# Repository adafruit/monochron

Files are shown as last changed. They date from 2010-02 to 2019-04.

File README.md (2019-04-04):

# MONOCHRON Clock kit - Open source clock platform, make clocks!

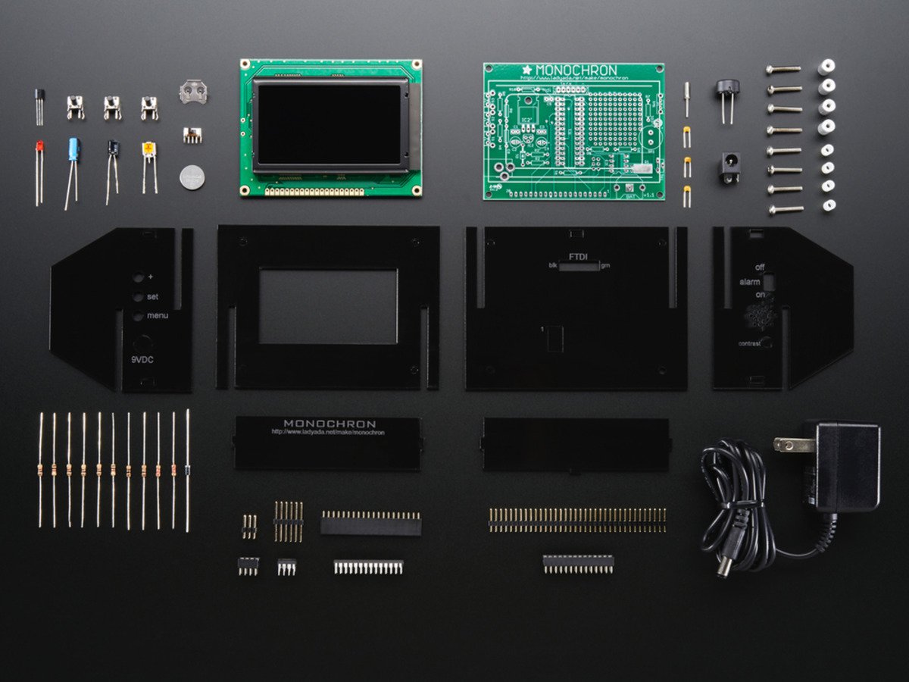
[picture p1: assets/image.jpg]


MONOCHRON® is a new clock kit from Adafruit! This easy kit is easily hackable to do whatever you wish, it's a clock platform - have fun!

- [128x64](https://learn.adafruit.com/system/assets/assets/000/010/412/original/lcd12864black.jpg) LCD (KS0108) - we special-ordered the black and white display!
- ATmega328 processor (we even stuck an 'arduino' stk500 bootloader on there too for hacking ease)
- [Laser cut enclosure in black acrylic](https://learn.adafruit.com/monochron/case-it)
- [Beeping/blinking alarm with 10 minute snooze](https://learn.adafruit.com/monochron/alarm)
- Battery backed-up real time clock ([DS1307](https://www.adafruit.com/partfinder/ic#rtc)) keeps time even when power is lost for years
- [European/US and 12/24 hour time display as well as date](https://learn.adafruit.com/monochron/date)
- [Completely open source hardware, all firmware, layout and CAD files are yours to mess with](https://learn.adafruit.com/monochron/download)
- Plenty of space for mods, a prototyping area for soldering stuff in

Comes with: clock kit (includes all parts, programmed chips and LCD), coin battery, enclosure, [9VDC power supply for 220V or 110V](https://www.adafruit.com/products/63)

The firmware shipped with the kit is for the Retro Arcade Table Tennis for Two as shown in the video below. We have other clock firmwares available on the project page if you would like to change the display. __This clock no longer includes the [FTDI Friend + extras](https://www.adafruit.com/products/284) for updating the MONOCHRON with new clocks__ We suggest picking one up if you want to reprogram the clock [(our tutorial for how to do this is on the MONOCHRON website.](https://learn.adafruit.com/monochron/updating).

You'll need some basic soldering & hand tools that are necessary to assemble it! The good news is that this is a pretty basic kit and even if its your first soldering project, it shouldn't take more than 2 or 3 hours to put together

For much more information including parts list, instructions, videos, etc. check out the [MONOCHRON website](https://learn.adafruit.com/monochron).

[MONOCHRON - open source retro clock](http://vimeo.com/9749504) from [adafruit industries](http://vimeo.com/adafruit) on [Vimeo](https://vimeo.com/).

- [Amanda 'w0z' Wozniak](http://praxical.blogspot.com/) - - designed the beautiful enclosure
- [Caitsith2](https://www.flickr.com/photos/48367508@N00/4389562355/) - beta-tested, and submitted some great firmware mods
- [Buro Vormkijgers](http://www.burovormkrijgers.nl/) - Inspired many people relive the joy of their retro-youth (__we are in no way associated with Buro Vormkijgers__, at the request of Sander Mulder on 4/10/2010 we've included a [link to his site here](http://www.sandermulder.com/pong_clock.html).)

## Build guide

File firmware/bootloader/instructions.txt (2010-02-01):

We're using the classic Arduino bootloader but for the internal 8MHz oscillator. 
Edit the makefile for your type of programmer and type in "make atmega328_prores_isp"

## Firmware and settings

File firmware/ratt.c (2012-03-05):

/* ***************************************************************************
// ratt.c - the time, init and main loop
// This code is distributed under the GNU Public License
//		which can be found at http://www.gnu.org/licenses/gpl.txt
//
**************************************************************************** */

#include <avr/io.h>      // this contains all the IO port definitions
#include <avr/interrupt.h>
#include <util/delay.h>
#include <avr/pgmspace.h>
#include <avr/eeprom.h>
#include <avr/wdt.h>
#include <string.h>
#include <i2c.h>
#include <stdlib.h>
#include "util.h"
#include "ratt.h"
#include "ks0108.h"
#include "glcd.h"


volatile uint8_t time_s, time_m, time_h;
volatile uint8_t old_h, old_m;
volatile uint8_t timeunknown = 1;
volatile uint8_t date_m, date_d, date_y;
volatile uint8_t alarming, alarm_on, alarm_tripped, alarm_h, alarm_m;
volatile uint8_t displaymode;
volatile uint8_t volume;
volatile uint8_t sleepmode = 0;
volatile uint8_t region;
volatile uint8_t time_format;
extern volatile uint8_t screenmutex;
volatile uint8_t minute_changed = 0, hour_changed = 0;
volatile uint8_t score_mode_timeout = 0;
volatile uint8_t score_mode = SCORE_MODE_TIME;
volatile uint8_t last_score_mode;

// These store the current button states for all 3 buttons. We can 
// then query whether the buttons are pressed and released or pressed
// This allows for 'high speed incrementing' when setting the time
extern volatile uint8_t last_buttonstate, just_pressed, pressed;
extern volatile uint8_t buttonholdcounter;

extern volatile uint8_t timeoutcounter;

// How long we have been snoozing
uint16_t snoozetimer = 0;

SIGNAL(TIMER1_OVF_vect) {
  PIEZO_PORT ^= _BV(PIEZO);
}

volatile uint16_t millis = 0;
volatile uint16_t animticker, alarmticker;
SIGNAL(TIMER0_COMPA_vect) {
  if (millis)
    millis--;
  if (animticker)
    animticker--;

  if (alarming && !snoozetimer) {
    if (alarmticker == 0) {
      alarmticker = 300;
      if (TCCR1B == 0) {
	TCCR1A = 0; 
	TCCR1B =  _BV(WGM12) | _BV(CS10); // CTC with fastest timer
	TIMSK1 = _BV(TOIE1) | _BV(OCIE1A);
	OCR1A = (F_CPU / ALARM_FREQ) / 2;
      } else {
	TCCR1B = 0;
	// turn off piezo
	PIEZO_PORT &= ~_BV(PIEZO);
      }
    }
    alarmticker--;    
  }
}

void init_eeprom(void) {	//Set eeprom to a default state.
  if(eeprom_read_byte((uint8_t *)EE_INIT) != EE_INITIALIZED) {
    eeprom_write_byte((uint8_t *)EE_ALARM_HOUR, 8);
    eeprom_write_byte((uint8_t *)EE_ALARM_MIN, 0);
    eeprom_write_byte((uint8_t *)EE_BRIGHT, OCR2A_VALUE);
    eeprom_write_byte((uint8_t *)EE_VOLUME, 1);
    eeprom_write_byte((uint8_t *)EE_REGION, REGION_US);
    eeprom_write_byte((uint8_t *)EE_TIME_FORMAT, TIME_12H);
    eeprom_write_byte((uint8_t *)EE_SNOOZE, 10);
    eeprom_write_byte((uint8_t *)EE_INIT, EE_INITIALIZED);
  }
}

int main(void) {
  uint8_t inverted = 0;
  uint8_t mcustate;
  uint8_t display_date = 0;

  // check if we were reset
  mcustate = MCUSR;
  MCUSR = 0;
  
  //Just in case we were reset inside of the glcd init function
  //which would happen if the lcd is not plugged in. The end result
  //of that, is it will beep, pause, for as long as there is no lcd
  //plugged in.
  wdt_disable();

  // setup uart
  uart_init(BRRL_192);
  DEBUGP("RATT Clock");

  // set up piezo
  PIEZO_DDR |= _BV(PIEZO);

  DEBUGP("clock!");
  clock_init();
  init_crand();	//Initialize the seed based upon current time.  Very first value discarded.
  //beep(4000, 100);

  init_eeprom();
  region = eeprom_read_byte((uint8_t *)EE_REGION);
  time_format = eeprom_read_byte((uint8_t *)EE_TIME_FORMAT);
  DEBUGP("buttons!");
  initbuttons();

  setalarmstate();

  // setup 1ms timer on timer0
  TCCR0A = _BV(WGM01);
  TCCR0B = _BV(CS01) | _BV(CS00);
  OCR0A = 125;
  TIMSK0 |= _BV(OCIE0A);

  // turn backlight on
  DDRD |= _BV(3);
#ifndef BACKLIGHT_ADJUST
  PORTD |= _BV(3);
#else
  TCCR2A = _BV(COM2B1); // PWM output on pin D3
  TCCR2A |= _BV(WGM21) | _BV(WGM20); // fast PWM
  TCCR2B |= _BV(WGM22);
  OCR2A = OCR2A_VALUE;
  OCR2B = eeprom_read_byte((uint8_t *)EE_BRIGHT);
#endif

  DDRB |= _BV(5);
  beep(4000, 100);
  
  //glcdInit locks and disables interrupts in one of its functions.  If the LCD is not
  //plugged in, glcd will run forever.  For good reason, it would be desirable to know
  //that the LCD is plugged in and working correctly as a result.  This is why we are
  //using a watch dog timer.  The lcd should initialized in way less than 500 ms.
  wdt_enable(WDTO_2S);
  glcdInit();
  glcdClearScreen();

  initanim();
  initdisplay(0);

  while (1) {
    animticker = ANIMTICK_MS;

    // check buttons to see if we have interaction stuff to deal with
	if(just_pressed && alarming)
	{
	  just_pressed = 0;
	  setsnooze();
	}
	if(display_date==1 && !score_mode_timeout)
	{
		display_date=3;
		score_mode = SCORE_MODE_DATELONG;
	    score_mode_timeout = 3;
	    setscore();
	}
	else if(display_date==2 && !score_mode_timeout)
	{
		display_date=3;
		score_mode = SCORE_MODE_DATE;
	    score_mode_timeout = 3;
	    setscore();
	}
	else if(display_date==3 && !score_mode_timeout)
	{
		display_date=0;
		score_mode = SCORE_MODE_YEAR;
	    score_mode_timeout = 3;
	    setscore();
	}
	/*if(display_date && !score_mode_timeout)
	{
	  if(last_score_mode == SCORE_MODE_DATELONG)
	  {
	    score_mode = SCORE_MODE_DOW;
	    score_mode_timeout = 3;
	    setscore();
	  }
	  
	  else if(last_score_mode == SCORE_MODE_DOW)
	  {
	    score_mode = SCORE_MODE_DATE;
	    score_mode_timeout = 3;
	    setscore();
	  }
	  else if(last_score_mode == SCORE_MODE_DATE)
	  {
	    score_mode = SCORE_MODE_YEAR;
	    score_mode_timeout = 3;
	    setscore();
	    display_date = 0;
	  }
	  
	}*/
	/*if(display_date && !score_mode_timeout)
	{
	  score_mode = SCORE_MODE_YEAR;
	  score_mode_timeout = 3;
	  setscore();
	  display_date = 0;
	}*/

    //Was formally set for just the + button.  However, because the Set button was never
    //accounted for, If the alarm was turned on, and ONLY the set button was pushed since then,
    //the alarm would not sound at alarm time, but go into a snooze immediately after going off.
    //This could potentially make you late for work, and had to be fixed.
	if (just_pressed & 0x6) {
	  just_pressed = 0;
	  if((region == REGION_US) || (region == REGION_EU)) {
	  	display_date = 3;
	  	score_mode = SCORE_MODE_DATE;
	  }
	  else if ((region == DOW_REGION_US) || (region == DOW_REGION_EU)) {
	  	display_date = 2;
	  	score_mode = SCORE_MODE_DOW;
	  }
	  else if (region == DATELONG) {
	  	display_date = 3;
	  	score_mode = SCORE_MODE_DATELONG;
	  }
	  else {
	  	display_date = 1;
	  	score_mode = SCORE_MODE_DOW;
	  }
	  score_mode_timeout = 3;
	  setscore();
	}

    if (just_pressed & 0x1) {
      just_pressed = 0;
      display_date = 0;
      score_mode = SCORE_MODE_TIME;
      score_mode_timeout = 0;
      setscore();
      switch(displaymode) {
      case (SHOW_TIME):
	displaymode = SET_ALARM;
	set_alarm();
	break;
      case (SET_ALARM):
	displaymode = SET_TIME;
	set_time();
	timeunknown = 0;
	break;
      case SET_TIME:
	displaymode = SET_DATE;
	set_date();
	break;
      case SET_DATE:
	displaymode = SET_REGION;
	set_region();
	break;
#ifdef BACKLIGHT_ADJUST
	  case SET_REGION:
	displaymode = SET_BRIGHTNESS;
	set_backlight();
	break;
#endif
      default:
	displaymode = SHOW_TIME;
	glcdClearScreen();
	initdisplay(0);
      }

      if (displaymode == SHOW_TIME) {
	glcdClearScreen();
	initdisplay(0);
      }
    }

    step();
    if (displaymode == SHOW_TIME) {
      if (! inverted && alarming && (time_s & 0x1)) {
	inverted = 1;
	initdisplay(inverted);
      }
      else if ((inverted && ! alarming) || (alarming && inverted && !(time_s & 0x1))) {
	inverted = 0;
	initdisplay(0);
      } else {
	PORTB |= _BV(5);
	draw(inverted);
	PORTB &= ~_BV(5);
    }
  }
  
    while (animticker);
    //uart_getchar();  // you would uncomment this so you can manually 'step'
  }

  halt();
}


SIGNAL(TIMER1_COMPA_vect) {
  PIEZO_PORT ^= _BV(PIEZO);
}

void beep(uint16_t freq, uint8_t duration) {
  // use timer 1 for the piezo/buzzer 
  TCCR1A = 0; 
  TCCR1B =  _BV(WGM12) | _BV(CS10); // CTC with fastest timer
  TIMSK1 = _BV(TOIE1) | _BV(OCIE1A);
  OCR1A = (F_CPU / freq) / 2;
  _delay_ms(duration);
  TCCR1B = 0;
  // turn off piezo
  PIEZO_PORT &= ~_BV(PIEZO);
}

// This turns on/off the alarm when the switch has been
// set. It also displays the alarm time
void setalarmstate(void) {
  DEBUGP("a");
  if (ALARM_PIN & _BV(ALARM)) { 
    if (alarm_on) {
      // turn off the alarm
      alarm_on = 0;
      alarm_tripped = 0;
      snoozetimer = 0;
      if (alarming) {
	// if the alarm is going off, we should turn it off
	// and quiet the speaker
	DEBUGP("alarm off");
	alarming = 0;
	TCCR1B = 0;
	// turn off piezo
	PIEZO_PORT &= ~_BV(PIEZO);
      } 
    }
  } else {
    // Don't display the alarm/beep if we already have
    if  (!alarm_on) {
      // alarm on!
      alarm_on = 1;
      // reset snoozing
      snoozetimer = 0;
	  score_mode = SCORE_MODE_ALARM;
	  score_mode_timeout = 3;
	  setscore();
      DEBUGP("alarm on");
    }   
  }
}


void drawArrow(uint8_t x, uint8_t y, uint8_t l) {
  glcdFillRectangle(x, y, l, 1, ON);
  glcdSetDot(x+l-2,y-1);
  glcdSetDot(x+l-2,y+1);
  glcdSetDot(x+l-3,y-2);
  glcdSetDot(x+l-3,y+2);
}


void printnumber(uint8_t n, uint8_t inverted) {
  glcdWriteChar(n/10+'0', inverted);
  glcdWriteChar(n%10+'0', inverted);
}

uint8_t readi2ctime(void) {
  uint8_t regaddr = 0, r;
  uint8_t clockdata[8];
  
  // check the time from the RTC
  cli();
  r = i2cMasterSendNI(0xD0, 1, &regaddr);

  if (r != 0) {
    DEBUG(putstring("Reading i2c data: ")); DEBUG(uart_putw_dec(r)); DEBUG(putstring_nl(""));
    while(1) {
      sei();
      beep(4000, 100);
      _delay_ms(100);
      beep(4000, 100);
      _delay_ms(1000);
    }
  }

  r = i2cMasterReceiveNI(0xD0, 7, &clockdata[0]);
  sei();

  if (r != 0) {
    DEBUG(putstring("Reading i2c data: ")); DEBUG(uart_putw_dec(r)); DEBUG(putstring_nl(""));
    while(1) {
      beep(4000, 100);
      _delay_ms(100);
      beep(4000, 100);
      _delay_ms(1000);
    }
  }

  time_s = ((clockdata[0] >> 4) & 0x7)*10 + (clockdata[0] & 0xF);
  time_m = ((clockdata[1] >> 4) & 0x7)*10 + (clockdata[1] & 0xF);
  if (clockdata[2] & _BV(6)) {
    // "12 hr" mode
    time_h = ((clockdata[2] >> 5) & 0x1)*12 + 
      ((clockdata[2] >> 4) & 0x1)*10 + (clockdata[2] & 0xF);
  } else {
    time_h = ((clockdata[2] >> 4) & 0x3)*10 + (clockdata[2] & 0xF);
  }
  
  date_d = ((clockdata[4] >> 4) & 0x3)*10 + (clockdata[4] & 0xF);
  date_m = ((clockdata[5] >> 4) & 0x1)*10 + (clockdata[5] & 0xF);
  date_y = ((clockdata[6] >> 4) & 0xF)*10 + (clockdata[6] & 0xF);

  return clockdata[0] & 0x80;
}

void writei2ctime(uint8_t sec, uint8_t min, uint8_t hr, uint8_t day,
		  uint8_t date, uint8_t mon, uint8_t yr) {
  uint8_t clockdata[8] = {0,0,0,0,0,0,0,0};

  clockdata[0] = 0; // address
  clockdata[1] = i2bcd(sec);  // s
  clockdata[2] = i2bcd(min);  // m
  clockdata[3] = i2bcd(hr); // h
  clockdata[4] = i2bcd(day);  // day
  clockdata[5] = i2bcd(date);  // date
  clockdata[6] = i2bcd(mon);  // month
  clockdata[7] = i2bcd(yr); // year
  
  cli();
  uint8_t r = i2cMasterSendNI(0xD0, 8, &clockdata[0]);
  sei();

  //DEBUG(putstring("Writing i2c data: ")); DEBUG(uart_putw_dec()); DEBUG(putstring_nl(""));

  if (r != 0) {
    while(1) {
      beep(4000, 100);
      _delay_ms(100);
      beep(4000, 100);
      _delay_ms(1000);
    }
  }

}

// runs at about 30 hz
uint8_t t2divider1 = 0, t2divider2 = 0;
SIGNAL (TIMER2_OVF_vect) {
  wdt_reset();
#ifdef BACKLIGHT_ADJUST
  if (t2divider1 == TIMER2_RETURN) {
#else
  if (t2divider1 == 5) {
#endif
    t2divider1 = 0;
  } else {
    t2divider1++;
    return;
  }

  //This occurs at 6 Hz

  uint8_t last_s = time_s;
  uint8_t last_m = time_m;
  uint8_t last_h = time_h;

  readi2ctime();
  
  if (time_h != last_h) {
    hour_changed = 1; 
    old_h = last_h;
    old_m = last_m;
  } else if (time_m != last_m) {
    minute_changed = 1;
    old_m = last_m;
  }

  if (time_s != last_s) {
    if(alarming && snoozetimer)
	  snoozetimer--;

    if(score_mode_timeout) {
	  score_mode_timeout--;
	  if(!score_mode_timeout) {
	  	last_score_mode = score_mode;
	    score_mode = SCORE_MODE_TIME;
	    if(hour_changed) {
	      time_h = old_h;
	      time_m = old_m;
	    } else if (minute_changed) {
	      time_m = old_m;
	    }
	    setscore();
	    if(hour_changed || minute_changed) {
	      time_h = last_h;
	      time_m = last_m;
	    }
	  }
	}


    DEBUG(putstring("**** "));
    DEBUG(uart_putw_dec(time_h));
    DEBUG(uart_putchar(':'));
    DEBUG(uart_putw_dec(time_m));
    DEBUG(uart_putchar(':'));
    DEBUG(uart_putw_dec(time_s));
    DEBUG(putstring_nl("****"));
  }

  if (((displaymode == SET_ALARM) ||
       (displaymode == SET_DATE) ||
       (displaymode == SET_REGION) ||
       (displaymode == SET_BRIGHTNESS)) &&
      (!screenmutex) ) {
      glcdSetAddress(MENU_INDENT + 10*6, 2);
      print_timehour(time_h, NORMAL);
      glcdWriteChar(':', NORMAL);
      printnumber(time_m, NORMAL);
      glcdWriteChar(':', NORMAL);
      printnumber(time_s, NORMAL);

      if (time_format == TIME_12H) {
	glcdWriteChar(' ', NORMAL);
	if (time_h >= 12) {
	  glcdWriteChar('P', NORMAL);
	} else {
	  glcdWriteChar('A', NORMAL);
	}
      }
  }

  // check if we have an alarm set
  if (alarm_on && (time_s == 0) && (time_m == alarm_m) && (time_h == alarm_h)) {
    DEBUG(putstring_nl("ALARM TRIPPED!!!"));
    alarm_tripped = 1;
  }
  
  //And wait till the score changes to actually set the alarm off.
  if(!minute_changed && !hour_changed && alarm_tripped) {
  	 DEBUG(putstring_nl("ALARM GOING!!!!"));
  	 alarming = 1;
  	 alarm_tripped = 0;
  }

  if (t2divider2 == 6) {
    t2divider2 = 0;
  } else {
    t2divider2++;
    return;
  }

  if (buttonholdcounter) {
    buttonholdcounter--;
  }

  if (timeoutcounter) {
    timeoutcounter--;
  }
}

uint8_t leapyear(uint16_t y) {
  return ( (!(y % 4) && (y % 100)) || !(y % 400));
}

void tick(void) {


}



inline uint8_t i2bcd(uint8_t x) {
  return ((x/10)<<4) | (x%10);
}


void clock_init(void) {
  // talk to clock
  i2cInit();


  if (readi2ctime()) {
    DEBUGP("uh oh, RTC was off, lets reset it!");
    writei2ctime(0, 0, 12, 0, 1, 1, 9); // noon 1/1/2009
   }

  readi2ctime();

  DEBUG(putstring("\n\rread "));
  DEBUG(uart_putw_dec(time_h));
  DEBUG(uart_putchar(':'));
  DEBUG(uart_putw_dec(time_m));
  DEBUG(uart_putchar(':'));
  DEBUG(uart_putw_dec(time_s));

  DEBUG(uart_putchar('\t'));
  DEBUG(uart_putw_dec(date_d));
  DEBUG(uart_putchar('/'));
  DEBUG(uart_putw_dec(date_m));
  DEBUG(uart_putchar('/'));
  DEBUG(uart_putw_dec(date_y));
  DEBUG(putstring_nl(""));

  alarm_m = eeprom_read_byte((uint8_t *)EE_ALARM_MIN) % 60;
  alarm_h = eeprom_read_byte((uint8_t *)EE_ALARM_HOUR) % 24;


  //ASSR |= _BV(AS2); // use crystal

  TCCR2B = _BV(CS22) | _BV(CS21) | _BV(CS20); // div by 1024
  // overflow ~30Hz = 8MHz/(255 * 1024)

  // enable interrupt
  TIMSK2 = _BV(TOIE2);

  sei();
}

void setsnooze(void) {
  //snoozetimer = eeprom_read_byte((uint8_t *)EE_SNOOZE);
  //snoozetimer *= 60; // convert minutes to seconds
  snoozetimer = MAXSNOOZE;
  TCCR1B = 0;
  // turn off piezo
  PIEZO_PORT &= ~_BV(PIEZO);
  DEBUGP("snooze");
  //displaymode = SHOW_SNOOZE;
  //_delay_ms(1000);
  displaymode = SHOW_TIME;
}

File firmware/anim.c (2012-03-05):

/* ***************************************************************************
// anim.c - the main animation and drawing code for MONOCHRON
// This code is distributed under the GNU Public License
//		which can be found at http://www.gnu.org/licenses/gpl.txt
//
**************************************************************************** */

#include <avr/io.h>      // this contains all the IO port definitions
#include <avr/interrupt.h>
#include <util/delay.h>
#include <avr/pgmspace.h>
#include <avr/eeprom.h>
#include <avr/wdt.h>
#include <string.h>
#include <stdlib.h>
#include <math.h>

#include "util.h"
#include "ratt.h"
#include "ks0108.h"
#include "glcd.h"
#include "font5x7.h"

extern volatile uint8_t time_s, time_m, time_h;
extern volatile uint8_t old_m, old_h;
extern volatile uint8_t date_m, date_d, date_y;
extern volatile uint8_t alarming, alarm_h, alarm_m;
extern volatile uint8_t time_format;
extern volatile uint8_t region;
extern volatile uint8_t score_mode;

uint8_t left_score, right_score;

float ball_x, ball_y;
float oldball_x, oldball_y;
float ball_dx, ball_dy;

int8_t rightpaddle_y, leftpaddle_y;
uint8_t oldleftpaddle_y, oldrightpaddle_y;
int8_t rightpaddle_dy, leftpaddle_dy;

extern volatile uint8_t minute_changed, hour_changed;

uint8_t redraw_time = 0;
uint8_t last_score_mode = 0;

uint32_t rval[2]={0,0};
uint32_t key[4];

void encipher(void) {  // Using 32 rounds of XTea encryption as a PRNG.
  unsigned int i;
  uint32_t v0=rval[0], v1=rval[1], sum=0, delta=0x9E3779B9;
  for (i=0; i < 32; i++) {
    v0 += (((v1 << 4) ^ (v1 >> 5)) + v1) ^ (sum + key[sum & 3]);
    sum += delta;
    v1 += (((v0 << 4) ^ (v0 >> 5)) + v0) ^ (sum + key[(sum>>11) & 3]);
  }
  rval[0]=v0; rval[1]=v1;
}

void init_crand() {
  uint32_t temp;
  key[0]=0x2DE9716E;  //Initial XTEA key. Grabbed from the first 16 bytes
  key[1]=0x993FDDD1;  //of grc.com/password.  1 in 2^128 chance of seeing
  key[2]=0x2A77FB57;  //that key again there.
  key[3]=0xB172E6B0;
  rval[0]=0;
  rval[1]=0;
  encipher();
  temp = alarm_h;
  temp<<=8;
  temp|=time_h;
  temp<<=8;
  temp|=time_m;
  temp<<=8;
  temp|=time_s;
  key[0]^=rval[1]<<1;
  encipher();
  key[1]^=temp<<1;
  encipher();
  key[2]^=temp>>1;
  encipher();
  key[3]^=rval[1]>>1;
  encipher();
  temp = alarm_m;
  temp<<=8;
  temp|=date_m;
  temp<<=8;
  temp|=date_d;
  temp<<=8;
  temp|=date_y;
  key[0]^=temp<<1;
  encipher();
  key[1]^=rval[0]<<1;
  encipher();
  key[2]^=rval[0]>>1;
  encipher();
  key[3]^=temp>>1;
  rval[0]=0;
  rval[1]=0;
  encipher();	//And at this point, the PRNG is now seeded, based on power on/date/time reset.
}

uint16_t crand(uint8_t type) {
  if((type==0)||(type>2))
  {
    wdt_reset();
    encipher();
    return (rval[0]^rval[1])&RAND_MAX;
  } else if (type==1) {
  	return ((rval[0]^rval[1])>>15)&3;
  } else if (type==2) {
  	return ((rval[0]^rval[1])>>17)&1;
  }
}

void setscore(void)
{
  if(score_mode != last_score_mode) {
    redraw_time = 1;
    last_score_mode = score_mode;
  }
  switch(score_mode) {
  	case SCORE_MODE_DOW:
  	  break;
  	case SCORE_MODE_DATELONG:
  	  right_score = date_d;
  	  break;
    case SCORE_MODE_TIME:
      if(alarming && (minute_changed || hour_changed)) {
      	if(hour_changed) {
	      left_score = old_h;
	      right_score = old_m;
	    } else if (minute_changed) {
	      right_score = old_m;
	    }
      } else {
        left_score = time_h;
        right_score = time_m;
      }
      break;
    case SCORE_MODE_DATE:
      if((region == REGION_US)||(region == DOW_REGION_US)) {
        left_score = date_m;
        right_score = date_d;
      } else {
        left_score = date_d;
        right_score = date_m;
      }
      break;
    case SCORE_MODE_YEAR:
      left_score = 20;
      right_score = date_y;
      break;
    case SCORE_MODE_ALARM:
      left_score = alarm_h;
      right_score = alarm_m;
      break;
  }
}

void initanim(void) {
  DEBUG(putstring("screen width: "));
  DEBUG(uart_putw_dec(GLCD_XPIXELS));
  DEBUG(putstring("\n\rscreen height: "));
  DEBUG(uart_putw_dec(GLCD_YPIXELS));
  DEBUG(putstring_nl(""));

  leftpaddle_y = 25;
  rightpaddle_y = 25;

  ball_x = (SCREEN_W / 2) - 1;
  ball_y = (SCREEN_H / 2) - 1;
  float angle = random_angle_rads();
  ball_dx = MAX_BALL_SPEED * cos(angle);
  ball_dy = MAX_BALL_SPEED * sin(angle);
}

void initdisplay(uint8_t inverted) {

  glcdFillRectangle(0, 0, GLCD_XPIXELS, GLCD_YPIXELS, inverted);
  
  // draw top 'line'
  glcdFillRectangle(0, 0, GLCD_XPIXELS, 2, ! inverted);
  
  // bottom line
  glcdFillRectangle(0, GLCD_YPIXELS - 2, GLCD_XPIXELS, 2, ! inverted);

  // left paddle
  glcdFillRectangle(LEFTPADDLE_X, leftpaddle_y, PADDLE_W, PADDLE_H, ! inverted);
  // right paddle
  glcdFillRectangle(RIGHTPADDLE_X, rightpaddle_y, PADDLE_W, PADDLE_H, ! inverted);
      
	//left_score = time_h;
	//right_score = time_m;
	setscore();

  // time
	if ((time_format == TIME_12H) && ((score_mode == SCORE_MODE_TIME) || (score_mode == SCORE_MODE_ALARM)))
		drawbigdigit(DISPLAY_H10_X, DISPLAY_TIME_Y, ((left_score + 23)%12 + 1)/10, inverted);
  else 
    drawbigdigit(DISPLAY_H10_X, DISPLAY_TIME_Y, left_score/10, inverted);
  
	if ((time_format == TIME_12H) && ((score_mode == SCORE_MODE_TIME) || (score_mode == SCORE_MODE_ALARM)))
		drawbigdigit(DISPLAY_H1_X, DISPLAY_TIME_Y, ((left_score + 23)%12 + 1)%10, inverted);
  else
    drawbigdigit(DISPLAY_H1_X, DISPLAY_TIME_Y, left_score%10, inverted);
  
  drawbigdigit(DISPLAY_M10_X, DISPLAY_TIME_Y, right_score/10, inverted);
  drawbigdigit(DISPLAY_M1_X, DISPLAY_TIME_Y, right_score%10, inverted);

  drawmidline(inverted);
}
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

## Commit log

2010-01-31 moving everything to git
    [RATTclock.ods, ratt.brd, ratt.sch]
2010-01-31 Cleaned up the .h and commented all the consts
    [RATTclock.ods]
2010-01-31 replaced most parts with the adafruit lib parts
    [ratt.brd, ratt.sch]
2010-02-01 Fixed a rare snooze related bug, that could cause the alarm to sound 10 minutes later than expected
    [ratt.c]
2010-02-01 alarm blinking no longer causes score to change too soon.
    [anim.c, ratt.c]
2010-02-01 debugging lines inserted in DEBUG/if(DEBUGGING) statements.
2010-02-01 foobar'd the ball placement code by mistake.
    [anim.c]
2010-02-01 fixed compiler complaints which also fixed the menu glitching (mutex wasnt checked properly!)
    [anim.c, ratt.c, ratt.h]
2010-02-01 CorelDraw file of enclosure
2010-02-01 alarm tripping flag now correctly turned off when alarm is turned off.
    [ratt.c]
2010-02-04 glcdinit locks up forever if no lcd is plugged in. Added a WDT to reset/beep/reset/beep, when no lcd is plugged in.
    [ratt.c]
2010-02-12 Fixed a menu bug, regarding backlight mode. (has no effect if backlight mode not defined.)
    [ratt.brd, ratt.sch]
2010-02-17 Fixed another backlight setting related bug, still no effect if define not used.
    [ratt.c]
2010-02-17 rand() replaced with xtea, seeded with current time on powerup.
    [anim.c, ratt.h]
2010-02-18 Fixed a race condition related to score redrawing.
    [anim.c]
2010-02-20 fixed some resistor values and LCD footprint
    [ratt.brd, ratt.sch]
2010-02-20 fixed bug in time setting bootloader is now nicer, blinks backlight to indicate
    [ATmegaBOOT_168.c, ratt.c]
2010-08-07 Fixed a rare bug that causes a total lockup, while setting the date/time. (It was due to an interrupt happening in the middle of writei2ctime, that calls readi2ctime. (The write was not quite finishe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
    [ratt.c]
2010-08-21 Another readi2ctime() bug cropped up, while fixing the i2c interruption bug. Fixed.
    [ratt.c]
2012-03-05 Enclosure in SVG
2012-03-23 Added 10K pullup to reset line
    [ratt.brd, ratt.sch]
